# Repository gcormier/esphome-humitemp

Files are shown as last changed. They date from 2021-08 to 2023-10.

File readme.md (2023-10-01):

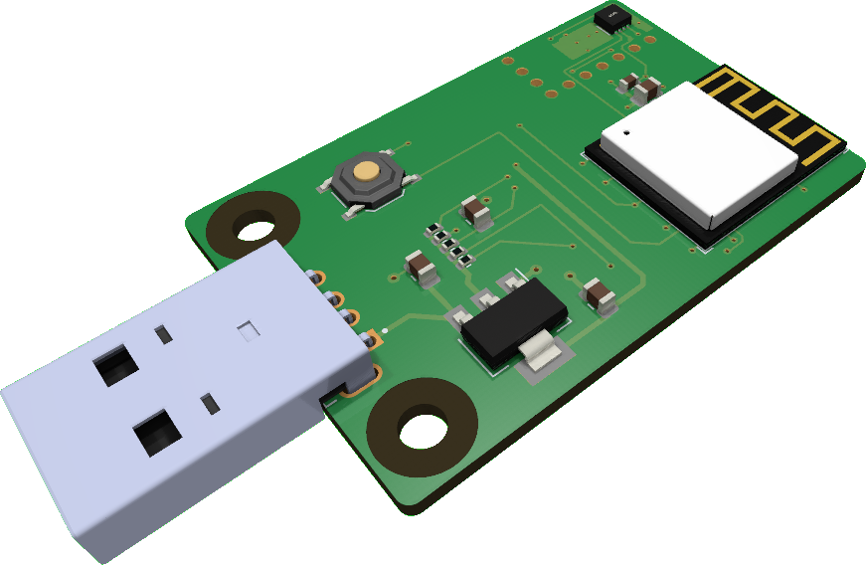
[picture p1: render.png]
 



# esphome-humitemp
- SHT3x temperature/humidity sensor
- ESP32-C3
- NEW: Native USB-C programming support (hold button 1st time)
- Or, backup/legacy programming header for [eflashy32](https://github.com/gcormier/eflashy32)
- Powered by 5V USB
- Designed for `esphome` but can be flashed with anything you want

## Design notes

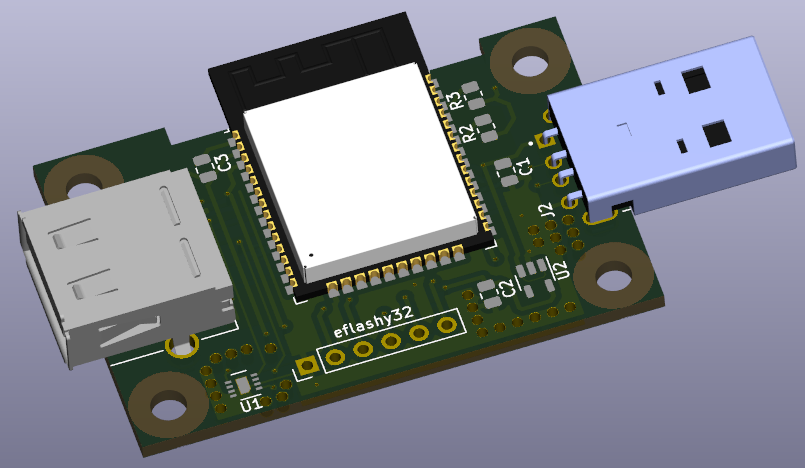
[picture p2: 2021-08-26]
esphome-humitemp1.png

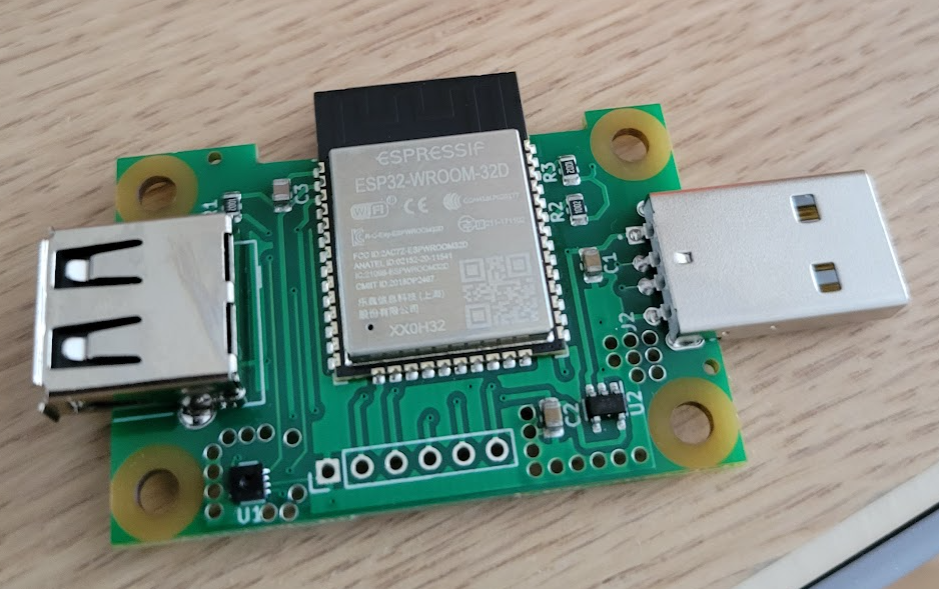
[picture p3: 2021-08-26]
esphome-humitemp2.png

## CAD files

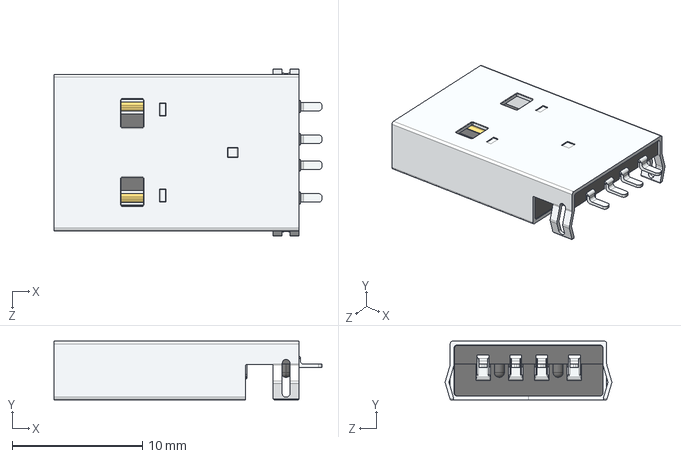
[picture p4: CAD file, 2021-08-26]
pcb/U217-041N-4BV81.step
20.6 x 4.50 x 12.8 mm

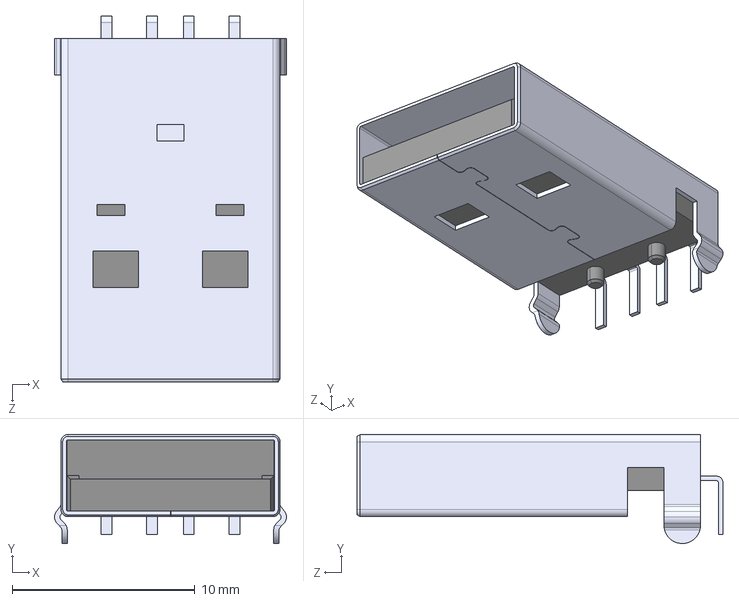
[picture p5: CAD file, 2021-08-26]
pcb/48037-0001.step
12.7 x 5.97 x 20.0 mm

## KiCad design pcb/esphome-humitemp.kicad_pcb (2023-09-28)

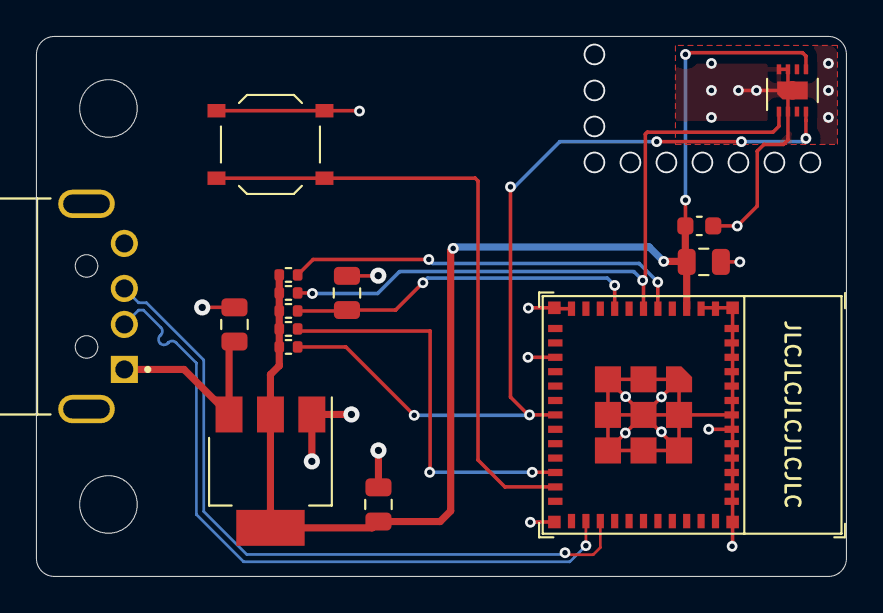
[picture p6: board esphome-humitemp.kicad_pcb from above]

Board: 2 copper layers, 45.0 x 30.0 mm, 17 parts (0 on the bottom side), 11 nets.

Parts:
C1, C2: 1uF; C_0805_2012Metric
C4, C6: 10u; C_0805_2012Metric
C5: 0.1u; C_0603_1608Metric
H1, H2: MountingHole; MountingHole_3.2mm_M3
J2: USB_IN; MOLEX_48037-0001
R2, R3, R4, R5, R6: 10k; R_0402_1005Metric
SW1: RESET; SW_Push_1P1T_XKB_TS-1187A
U1: SHT3x; Sensirion_DFN-8-1EP_2.5x2.5mm_P0.5mm_EP1.1x1.7mm
U3: AMS1117-3.3; SOT-223-3_TabPin2
U4: ESP32-C3-MINI-1

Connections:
+3V3: C2.1, C5.2, C6.2, R2.1, R3.1, R4.1, R5.1, R6.1, U1.5 (VDD), U3.2 (VO), U4.3 (3V3)
/EN: C4.2, R4.2, U4.8 (EN/CHIP_PU)
/GPIO0: SW1.1 (A), U4.23 (GPIO9)
D+: J2.3 (D+), U4.27 (GPIO19/USB_D+)
D-: J2.2 (D-), U4.26 (GPIO18/USB_D-)
GND: C1.2, C2.2, C4.1, C5.1, C6.1, J2.4 (GND), SW1.2 (B), U1.2 (ADDR), U1.7 (R), U1.8 (VSS), U1.9 (VSS), U3.1 (GND), U4.1 (GND), U4.2 (GND), U4.11 (GND), U4.14 (GND), U4.36 (GND), U4.37 (GND), U4.38 (GND), U4.39 (GND), U4.40 (GND), U4.41 (GND), U4.42 (GND), U4.43 (GND), U4.44 (GND), U4.45 (GND), U4.46 (GND), U4.47 (GND), U4.48 (GND), U4.49 (GND), U4.50 (GND), U4.51 (GND), U4.52 (GND), U4.53 (GND)
unnamed: R5.2, U4.5 (GPIO2/ADC1_CH2)
unnamed: R6.2, U4.22 (GPIO8)
SCL: R3.2, U1.4 (SCL), U4.18 (GPIO4/ADC1_CH4)
SDA: R2.2, U1.1 (SDA), U4.6 (GPIO3/ADC1_CH3)
VBUS: C1.1, J2.1 (VBUS), U3.3 (VI)

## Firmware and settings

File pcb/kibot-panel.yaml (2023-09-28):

kibot:
  version: 1

preflight:
  check_zone_fills: true
  fill_zones: true

filters:
  - name: only_jlc_parts
    comment: 'Only parts with JLC (LCSC) code'
    type: generic
    include_only:
      - column: 'LCSC'
        regex: '^.+'

variants:
  - name: rotated
    comment: 'Just a place holder for the rotation filter'
    type: kibom
    variant: rotated
    pre_transform: _rot_footprint

outputs:
  - name: 'panel'
    type: panelize
    options:
      title: '+ (Panel)'
      units: mm
      configs:
        - layout:
            rows: 3
            cols: 2
            space: 4mm
            alternation: cols
          tabs:
            type: fixed
            width: 5mm
            vcount: 2
            #hcount: 1
          cuts:
            type: vcuts
            layer: Edge.Cuts
          framing:
            type: railstb
            width: 5mm
            space: 3mm
            fillet: 1mm
            mintotalwidth: 70mm
            mintotalheight: 70mm
          tooling:
            type: 4hole
            hoffset: 2.5
            voffset: 2.5
            size: 1.152
          fiducials:
            type: 4fid
            hoffset: 5
            voffset: 3.85
            coppersize: 1
            opening: 2
          text:
            type: simple
            text: JLCJLCJLCJLC
            anchor: mt
            voffset: 2.5
            hjustify: center
            vjustify: center
          text2:
            type: simple
            text: Design created on {date} - <<hash>>
            anchor: mb
            voffset: -2.5
            hjustify: center
            vjustify: center
          post:
            refillzones: true
            millradius: 1mm

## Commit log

2021-08-26 move thermal via slightly to avoid bad programmer placement
    [esphome-humitemp.kicad_pcb]
2023-09-19 v2 ecad
    [ESP32-WROOM-32D--3DModel-STEP-56544.STEP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]
2023-09-19 fix a few issues
    [esphome-humitemp.kicad_pcb, esphome-humitemp.kicad_sch]
2023-09-19 add model
    [1001-011-01101.igs, 676433910.stp, esphome-humitemp.kicad_pcb]
2023-09-28 final tweaks
    [esphome-humitemp.kicad_pcb]
2023-09-28 rounded edges
    [esphome-humitemp.kicad_pcb]
2023-09-28 rotate and send it
    [esphome-humitemp.kicad_pcb]
2023-09-30 fix part number for 10k
    [esphome-humitemp.kicad_sch]
2023-12-22 button wakeup
